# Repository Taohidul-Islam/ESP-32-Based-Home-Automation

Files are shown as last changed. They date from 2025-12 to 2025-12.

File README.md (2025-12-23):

# ESP-32-Based-Home-Automation
<h2>This Board can turn any regular household electric switchboard into a smart Wi-Fi and Remote controlled switchboard.</h2>
<p>Here the board I designed is fail protected, meaning even if my electronic logic fails, the switchboard would work like a regular switchboard. The Automation Board is designed maintaining hierarchy. Meaning the Automation Board can only work only if the main switch from switch board is set to "on". In my logic I don't really turn anything "On". Everything is default "On" and "Off" by switchboard. I can just turn the things "Off" when the switch is "On" by triggering relay and turn the things back to it's default "On" position</p>
<p>N.B. IR remote control is currently unavailable and AC induction fan control channel can be faulty as it is not tested(will test soon).</p>

<P>Here are some screenshots of my PCB And Schematics</P>



Screenshot (96)
Screenshot (97)
Screenshot (98)
Screenshot (99)

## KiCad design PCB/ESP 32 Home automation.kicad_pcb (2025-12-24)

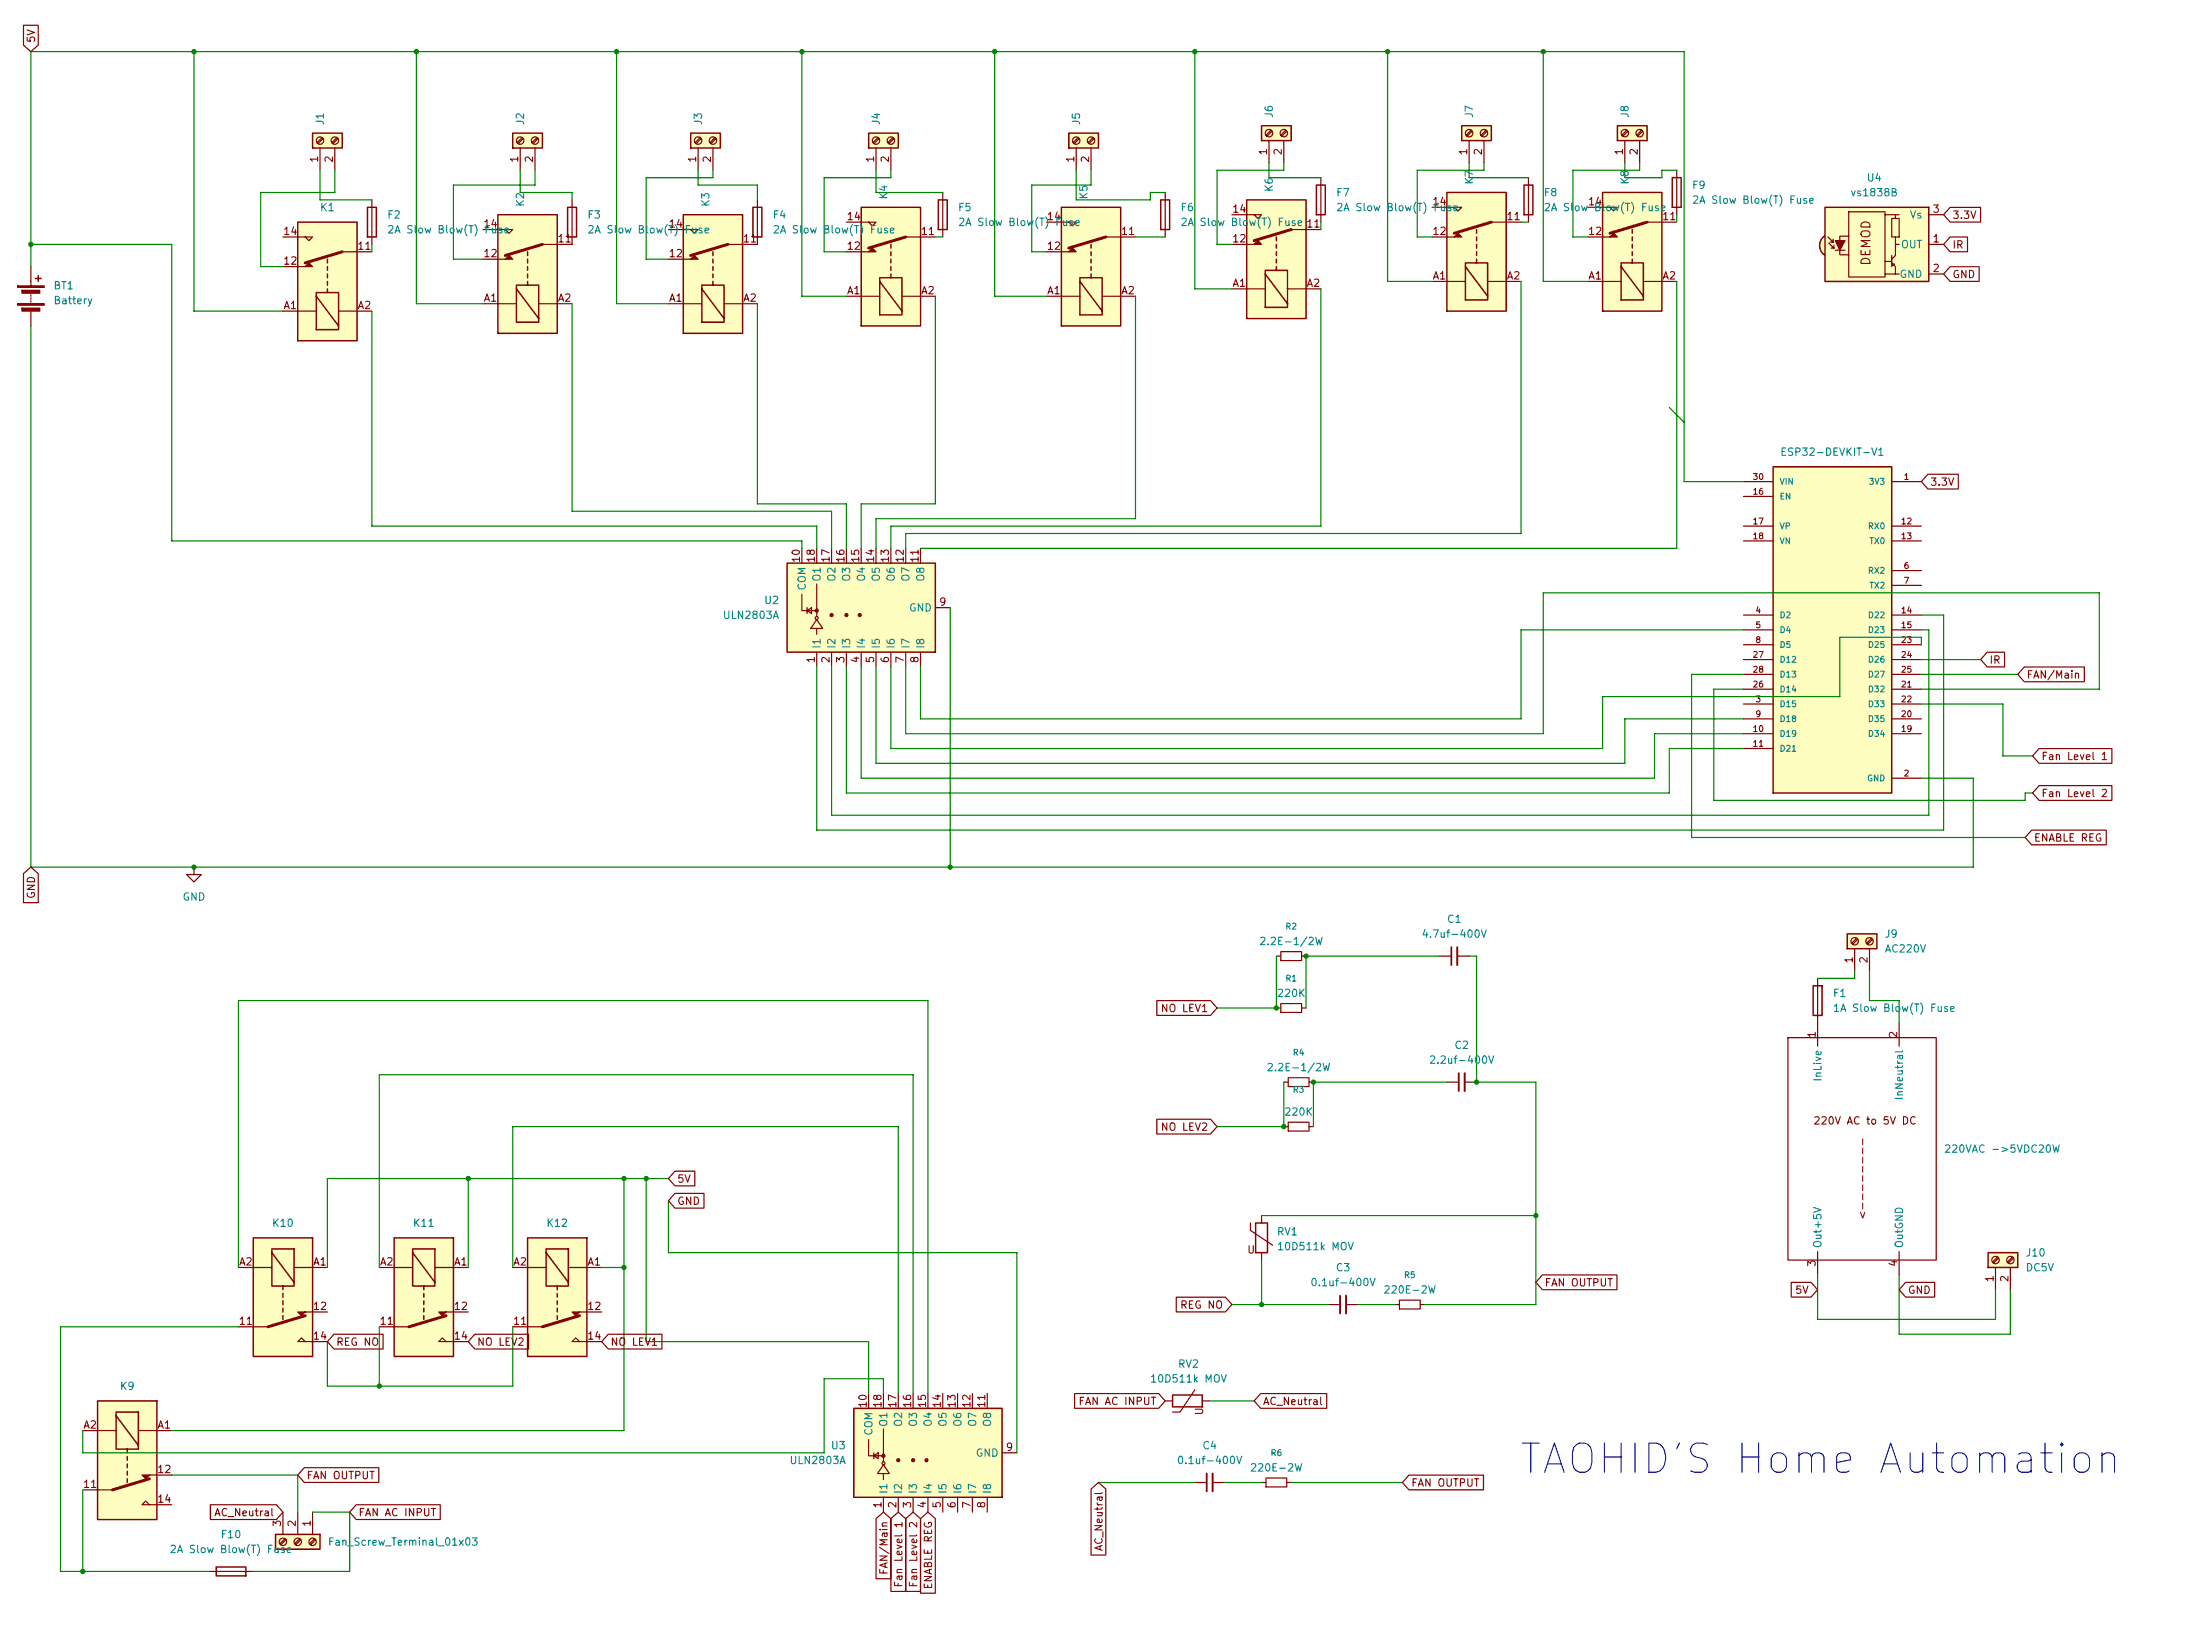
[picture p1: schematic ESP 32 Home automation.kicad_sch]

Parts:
Adapter/Charger1: 220VAC ->5VDC20W; ACtoDC power Adapter. 220V to 5V
BT1: Battery; TerminalBlock_MaiXu_MX126-5.0-02P_1x02_P5.00mm
C1: 4.7uf-400V; C_Rect_L32.0mm_W15.0mm_P27.00mm
C2: 2.2uf-400V; C_Rect_L27.0mm_W9.0mm_P22.00mm
C3, C4: 0.1uf-400V; C_Rect_L13.0mm_W6.5mm_P7.50mm_P10.00mm
F1: 1A Slow Blow(T) Fuse; Fuseholder_Littelfuse_100_series_5x20mm
F2, F3, F4, F5, F6, F7, F8, F9, F10: 2A Slow Blow(T) Fuse; Fuseholder_Littelfuse_100_series_5x20mm
J1, J2, J3, J4, J5, J6, J7, J8: Screw_Terminal_01x02; TerminalBlock_Phoenix_MKDS-1,5-2-5.08_1x02_P5.08mm_Horizont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
J9: AC220V; TerminalBlock_Phoenix_MKDS-1,5-2-5.08_1x02_P5.08mm_Horizont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
J10: DC5V; TerminalBlock_Phoenix_MKDS-1,5-2-5.08_1x02_P5.08mm_Horizont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
J11: Fan_Screw_Terminal_01x03; TerminalBlock_Phoenix_MKDS-1,5-3-5.08_1x03_P5.08mm_Horizont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
K1, K2, K3, K4, K5, K6, K7, K8, K9, K10, K11, K12: JQC-3FF-005-1Z; Relay_SPDT_Hongfa_JQC-3FF_0XX-1Z
R1, R3: 220K; R_Axial_DIN0309_L9.0mm_D3.2mm_P20.32mm_Horizontal
R2, R4: 2.2E-1/2W; R_Axial_DIN0309_L9.0mm_D3.2mm_P20.32mm_Horizontal
R5, R6: 220E-2W; R_Axial_DIN0309_L9.0mm_D3.2mm_P20.32mm_Horizontal
RV1, RV2: 10D511k MOV; RV_Disc_D12mm_W7.5mm_P7.5mm
U1: ESP32-DEVKIT-V1; MODULE_ESP32_DEVKIT_V1; PARTREV N/A
U2, U3: ULN2803A; DIP-18_W7.62mm_Socket_LongPads
U4: vs1838B; Vishay_MOLD-3Pin

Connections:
3.3V: U1.1 (3V3), U4.3 (Vs)
5V: Adapter/Charger1.3 (Out+5V), BT1.1 (+), J10.1, K1.A1, K2.A1, K3.A1, K4.A1, K5.A1, K6.A1, K7.A1, K8.A1, K9.A1, K10.A1, K11.A1, K12.A1, U1.30 (VIN), U2.10 (COM), U3.10 (COM)
AC_Neutral: C4.1, J11.3, RV2.2
ENABLE REG: U1.28 (D13), U3.4 (I4)
FAN AC INPUT: F10.2, J11.1, RV2.1
FAN OUTPUT: C1.2, C2.2, J11.2, K9.12, R5.2, R6.2, RV1.1
FAN/Main: U1.25 (D27), U3.1 (I1)
Fan Level 1: U1.22 (D33), U3.2 (I2)
Fan Level 2: U1.26 (D14), U3.3 (I3)
GND: Adapter/Charger1.4 (OutGND), BT1.2 (-), J10.2, U1.2 (GND), U1.29 (GND), U2.9 (GND), U3.9 (GND), U4.2 (GND)
IR: U1.24 (D26), U4.1 (OUT)
NO LEV1: K12.14, R1.1, R2.1
NO LEV2: K11.14, R3.1, R4.1
unnamed: Adapter/Charger1.1 (InLive), F1.1
unnamed: Adapter/Charger1.2 (InNeutral), J9.2
unnamed: C1.1, R1.2, R2.2
unnamed: C2.1, R3.2, R4.2
unnamed: C3.2, R5.1
unnamed: C4.2, R6.1
unnamed: F2.2, K1.11
unnamed: F3.2, K2.11
unnamed: F4.2, K3.11
unnamed: F5.2, K4.11
unnamed: F6.2, K5.11
unnamed: F7.2, K6.11
unnamed: F8.2, K7.11
unnamed: F9.2, K8.11
unnamed: F10.1, K9.11, K10.11
unnamed: F2.1, J1.1
unnamed: J1.2, K1.12
unnamed: F3.1, J2.1
unnamed: J2.2, K2.12
unnamed: F4.1, J3.1
unnamed: J3.2, K3.12
unnamed: F5.1, J4.1
unnamed: J4.2, K4.12
unnamed: F6.1, J5.1
unnamed: J5.2, K5.12
unnamed: F7.1, J6.1
unnamed: J6.2, K6.12
unnamed: F8.1, J7.1
unnamed: J7.2, K7.12
unnamed: F9.1, J8.1
unnamed: J8.2, K8.12
unnamed: F1.2, J9.1
unnamed: U1.5 (D4), U2.8 (I8)
unnamed: U1.9 (D18), U2.5 (I5)
unnamed: U1.10 (D19), U2.4 (I4)
unnamed: U1.11 (D21), U2.3 (I3)
unnamed: U1.14 (D22), U2.1 (I1)
unnamed: U1.15 (D23), U2.2 (I2)
unnamed: U1.23 (D25), U2.6 (I6)
unnamed: U1.21 (D32), U2.7 (I7)
unnamed: K1.A2, U2.18 (O1)
unnamed: K2.A2, U2.17 (O2)
unnamed: K3.A2, U2.16 (O3)
unnamed: K4.A2, U2.15 (O4)
unnamed: K5.A2, U2.14 (O5)
unnamed: K6.A2, U2.13 (O6)
unnamed: K7.A2, U2.12 (O7)
unnamed: K8.A2, U2.11 (O8)
unnamed: K9.A2, U3.18 (O1)
unnamed: K12.A2, U3.17 (O2)
unnamed: K11.A2, U3.16 (O3)
unnamed: K10.A2, U3.15 (O4)
REG NO: C3.1, K10.14, K11.11, K12.11, RV1.2

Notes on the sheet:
TAOHID'S Home Automation

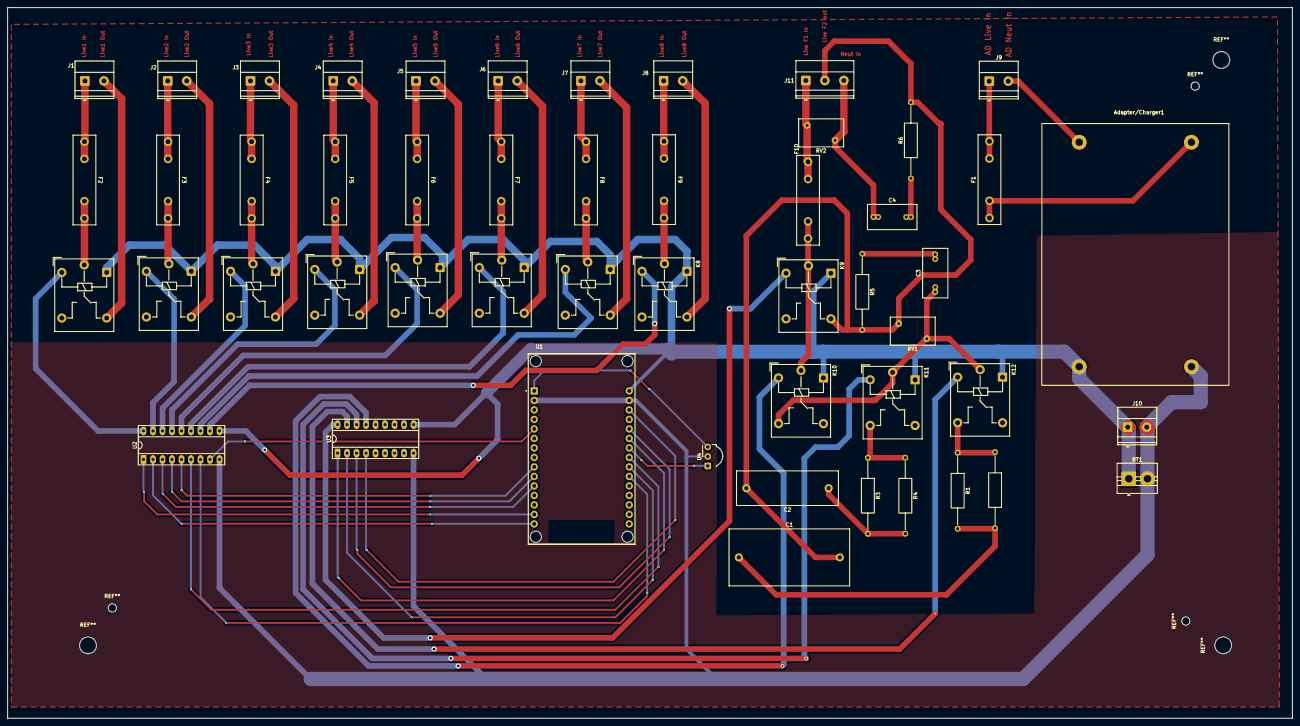
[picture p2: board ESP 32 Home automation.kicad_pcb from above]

Board: 2 copper layers, 343.5 x 190.0 mm, 51 parts (0 on the bottom side), 66 nets.

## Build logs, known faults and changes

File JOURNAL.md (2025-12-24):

<h1>Learned How to Design a PCB</h1>
<h2>December 11, 2025</h2>
<h3>Spent:2.8Hours</h3>
<p>Today through youtube, I learned how to design a PCB on Kikad and started building my first PCB design. Before I worked with breadboard circuitry but never designed a PCB. The one I am designing right now is not related to any project. It's just an tutorial piece. I am gonna make my main project PCB next day. The whole circuitry is on my head right now.
</p>




<h1>Completed my first PCB</h1>
<h2>December 12, 2025</h2>
<h3>Spent:2.5Hours</h3>
<p>Today I completed my basic learning on building PCB and built an mini inverter PCB watching a tutorial. I leant how to make Gerber file and what to send to PCB manufacturer to manufacture my PCB. I hope from the next day, I can start building my project PCB.
</p>



<h1>Started making Schematics, researched on how to control AC.</h1>
<h2>December 13, 2025</h2>
<h3>Spent time: 4 Hours</h3>
<p>Today I started building my project PCB and done research on how to control AC average voltage with a TRIAC and ESP 32. Bought some things to practically learn about TRIACS.
</p>
Today I started building my project PCB and done research on how to control AC average voltage with a TRIAC and ESP 32. Bought some things to practically learn about TRIACS.



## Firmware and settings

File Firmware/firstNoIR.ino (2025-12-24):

#include <WiFi.h>
#include <WebServer.h>
#include <Preferences.h>
#include <ESPmDNS.h>

// GPIO Pin Definitions
#define RELAY_1 22
#define RELAY_2 23
#define RELAY_3 21
#define RELAY_4 19
#define RELAY_5 18
#define RELAY_6 25
#define RELAY_7 32
#define RELAY_8 4

#define FAN_ON 27
#define FAN_LEV1 33
#define FAN_LEV2 14
#define FAN_LEV3 13

#define RESET_PIN 15  // Reset to AP mode button (pull to GND)

// AP Mode Configuration
const char* ap_ssid = "ESP32_SmartSwitch";
const char* ap_password = "12345678";
IPAddress ap_ip(192, 168, 4, 1);
IPAddress ap_gateway(192, 168, 4, 1);
IPAddress ap_subnet(255, 255, 255, 0);

// Static IP Configuration for Home WiFi
IPAddress static_ip(192, 168, 0, 200); // Change this to your desired static IP
IPAddress gateway(192, 168, 0, 1);     // Your router's gateway
IPAddress subnet(255, 255, 255, 0);
IPAddress dns(192, 168, 0, 1);

// Global Variables
WebServer server(80);
Preferences preferences;

bool relayStates[8] = {true, true, true, true, true, true, true, true}; // Default ON
bool fanOnState = true;  // Default ON
int fanLevel = 0;        // 0=OFF, 1=LEV1, 2=LEV2, 3=LEV3
bool useAPMode = true;
String storedSSID = "";
String storedPassword = "";
unsigned long lastStatusPrint = 0;

// GPIO Pins Array
const int relayPins[8] = {RELAY_1, RELAY_2, RELAY_3, RELAY_4, RELAY_5, RELAY_6, RELAY_7, RELAY_8};

void setup() {
  Serial.begin(115200);
  delay(1000);
  
  Serial.println("\n\n========================================");
  Serial.println("   ESP32 Smart Switchboard v1.0");
  Serial.println("========================================\n");
  
  // Initialize Preferences
  preferences.begin("wifi-config", false);
  storedSSID = preferences.getString("ssid", "");
  storedPassword = preferences.getString("password", "");
  useAPMode = preferences.getBool("useAP", true);
  
  Serial.println("Stored SSID: " + (storedSSID.length() > 0 ? storedSSID : "None"));
  Serial.println("Use AP Mode: " + String(useAPMode ? "Yes" : "No"));
  
  // Load saved states
  for(int i = 0; i < 8; i++) {
    relayStates[i] = preferences.getBool(("relay" + String(i)).c_str(), true);
  }
  fanOnState = preferences.getBool("fanOn", true);
  fanLevel = preferences.getInt("fanLevel", 0);
  
  // Initialize GPIO Pins
  initGPIO();
  applyAllStates();
  
  Serial.println("\n--- Network Configuration ---");
  
  // Start WiFi
  if (!useAPMode && storedSSID.length() > 0) {
    connectToWiFi();
  } else {
    startAPMode();
  }
  
  // Setup Web Server Routes
  setupRoutes();
  server.begin();
  
  Serial.println("\n========================================");
  Serial.println("   System Ready!");
  Serial.println("========================================\n");
}

void loop() {
  server.handleClient();
  
  // Print status every 10 seconds if in WiFi mode
  if(WiFi.getMode() == WIFI_STA && millis() - lastStatusPrint > 10000) {
    lastStatusPrint = millis();
    Serial.println("\n--- Status Update ---");
    Serial.print("WiFi Connected: ");
    Serial.println(WiFi.status() == WL_CONNECTED ? "YES" : "NO");
    Serial.print("IP Address: ");
    Serial.println(WiFi.localIP());
    Serial.print("Access at: http://");
    Serial.println(WiFi.localIP());
    Serial.print("Or via: http://smartswitch.local");
    Serial.println("\n-------------------\n");
  }
  
  // Check if reset button is pressed (pulled to GND)
  if(digitalRead(RESET_PIN) == LOW) {
    delay(50); // Debounce
    if(digitalRead(RESET_PIN) == LOW) {
      Serial.println("Reset button pressed! Switching to AP mode...");
      
      // Save AP mode preference
      preferences.putBool("useAP", true);
      
      delay(500);
      ESP.restart();
    }
  }
}

void initGPIO() {
  // Initialize all relay pins
  for(int i = 0; i < 8; i++) {
    pinMode(relayPins[i], OUTPUT);
  }
  
  // Initialize fan control pins
  pinMode(FAN_ON, OUTPUT);
  pinMode(FAN_LEV1, OUTPUT);
  pinMode(FAN_LEV2, OUTPUT);
  pinMode(FAN_LEV3, OUTPUT);
  
  // Initialize reset button with internal pull-up
  pinMode(RESET_PIN, INPUT_PULLUP);
}

void applyAllStates() {
  // Apply relay states (ON = LOW, OFF = HIGH)
  for(int i = 0; i < 8; i++) {
    digitalWrite(relayPins[i], relayStates[i] ? LOW : HIGH);
  }
  
  // Apply fan states
  digitalWrite(FAN_ON, fanOnState ? LOW : HIGH);
  
  if(fanOnState) {
    // Fan is ON, disable all levels
    digitalWrite(FAN_LEV1, LOW);
    digitalWrite(FAN_LEV2, LOW);
    digitalWrite(FAN_LEV3, LOW);
  } else {
    // Fan is OFF, apply level if selected
    applyFanLevel();
  }
}

void applyFanLevel() {
  // First, turn off all levels with delay
  digitalWrite(FAN_LEV1, LOW);
  delay(50);
  digitalWrite(FAN_LEV2, LOW);
  delay(50);
  digitalWrite(FAN_LEV3, LOW);
  delay(50);
  
  // Then turn on the selected level (if any)
  if(fanLevel == 1) {
    digitalWrite(FAN_LEV1, HIGH);
  } else if(fanLevel == 2) {
    digitalWrite(FAN_LEV2, HIGH);
  } else if(fanLevel == 3) {
    digitalWrite(FAN_LEV3, HIGH);
  }
}

void startAPMode() {
  Serial.println("Starting AP Mode...");
  WiFi.mode(WIFI_AP);
  WiFi.softAPConfig(ap_ip, ap_gateway, ap_subnet);
  WiFi.softAP(ap_ssid, ap_password);
  
  Serial.print("AP IP Address: ");
  Serial.println(WiFi.softAPIP());
  Serial.println("Connect to WiFi: " + String(ap_ssid));
  Serial.println("Navigate to: http://192.168.4.1");
}

void connectToWiFi() {
  Serial.println("Connecting to WiFi...");
  Serial.println("SSID: " + storedSSID);
  WiFi.mode(WIFI_STA);
  WiFi.config(static_ip, gateway, subnet, dns);
  WiFi.begin(storedSSID.c_str(), storedPassword.c_str());
  
  int attempts = 0;
  while (WiFi.status() != WL_CONNECTED && attempts < 30) {
    delay(500);
    Serial.print(".");
    attempts++;
  }
  
  if (WiFi.status() == WL_CONNECTED) {
    Serial.println("\nConnected to WiFi!");
    Serial.print("Static IP Address: ");
    Serial.println(WiFi.localIP());
    Serial.print("Gateway: ");
    Serial.println(WiFi.gatewayIP());
    Serial.print("Subnet: ");
    Serial.println(WiFi.subnetMask());
    Serial.print("DNS: ");
    Serial.println(WiFi.dnsIP());
    
    // Setup mDNS
    if(MDNS.begin("smartswitch")) {
      Serial.println("mDNS started: http://smartswitch.local");
    }
  } else {
    Serial.println("\n❌ Failed to connect to WiFi!");
    Serial.println("Reason: " + String(WiFi.status()));
    Serial.println("Falling back to AP Mode...");
    
    // Clear saved credentials and switch to AP mode
    preferences.putBool("useAP", true);
    startAPMode();
  }
}

void setupRoutes() {
  server.on("/", HTTP_GET, handleRoot);
  server.on("/config", HTTP_GET, handleConfig);
  server.on("/savewifi", HTTP_POST, handleSaveWiFi);
  server.on("/useap", HTTP_POST, handleUseAP);
  server.on("/toggle", HTTP_POST, handleToggle);
  server.on("/fanon", HTTP_POST, handleFanOn);
  server.on("/fanlevel", HTTP_POST, handleFanLevel);
  server.on("/status", HTTP_GET, handleStatus);
}

void handleRoot() {
  String html = "<!DOCTYPE html><html><head>";
  html += "<meta name='viewport' content='width=device-width, initial-scale=1.0'>";
  html += "<title>Smart Switchboard</title>";
  html += "<style>";
  html += "body{font-family:Arial;margin:0;padding:20px;background:#f0f0f0;}";
  html += ".container{max-width:600px;margin:0 auto;background:white;padding:20px;border-radius:10px;box-shadow:0 2px 10px rgba(0,0,0,0.1);}";
  html += "h1{color:#333;text-align:center;margin-bottom:30px;}";
  html += ".switch-row{display:flex;justify-content:space-between;align-items:center;padding:15px;border-bottom:1px solid #eee;}";
  html += ".switch-row:last-child{border-bottom:none;}";
  html += ".label{font-size:16px;font-weight:500;}";
  html += ".toggle{position:relative;width:60px;height:30px;background:#ccc;border-radius:30px;cursor:pointer;transition:0.3s;}";
  html += ".toggle.on{background:#4CAF50;}";
  html += ".toggle-slider{position:absolute;top:3px;left:3px;width:24px;height:24px;background:white;border-radius:50%;transition:0.3s;}";
  html += ".toggle.on .toggle-slider{left:33px;}";
  html += ".fan-section{background:#f9f9f9;padding:15px;margin-top:20px;border-radius:8px;}";
  html += ".level-buttons{display:flex;gap:10px;margin-top:10px;}";
  html += ".level-btn{flex:1;padding:10px;border:none;border-radius:5px;cursor:pointer;font-weight:bold;transition:0.3s;}";
  html += ".level-btn.active{background:#2196F3;color:white;}";
  html += ".level-btn.inactive{background:#e0e0e0;color:#666;}";
  html += ".config-btn{display:block;width:100%;padding:15px;margin-top:20px;background:#FF9800;color:white;border:none;border-radius:5px;font-size:16px;cursor:pointer;}";
  html += ".config-btn:hover{background:#F57C00;}";
  html += ".info{text-align:center;margin-top:20px;color:#666;font-size:14px;}";
  html += "</style>";
  html += "</head><body>";
  html += "<div class='container'>";
  html += "<h1>Smart Switchboard</h1>";
  
  // Regular switches
  for(int i = 0; i < 8; i++) {
    html += "<div class='switch-row'>";
    html += "<span class='label'>Switch " + String(i+1) + "</span>";
    html += "<div class='toggle " + String(relayStates[i] ? "on" : "") + "' onclick='toggleRelay(" + String(i) + ")'>";
    html += "<div class='toggle-slider'></div></div></div>";
  }
  
  // Fan section
  html += "<div class='fan-section'>";
  html += "<div class='switch-row'>";
  html += "<span class='label'>Fan Power</span>";
  html += "<div class='toggle " + String(fanOnState ? "on" : "") + "' onclick='toggleFan()'>";
  html += "<div class='toggle-slider'></div></div></div>";
  
  if(!fanOnState) {
    html += "<div class='level-buttons'>";
    html += "<button class='level-btn " + String(fanLevel == 1 ? "active" : "inactive") + "' onclick='setFanLevel(1)'>Level 1</button>";
    html += "<button class='level-btn " + String(fanLevel == 2 ? "active" : "inactive") + "' onclick='setFanLevel(2)'>Level 2</button>";
    html += "<button class='level-btn " + String(fanLevel == 3 ? "active" : "inactive") + "' onclick='setFanLevel(3)'>Level 3</button>";
    html += "</div>";
  }
  html += "</div>";
  
  html += "<button class='config-btn' onclick='location.href=\"/config\"'>WiFi Configuration</button>";
  
  html += "<div class='info'>";
  if(WiFi.getMode() == WIFI_AP) {
    html += "Mode: Access Point<br>IP: " + WiFi.softAPIP().toString();
  } else {
    html += "Mode: WiFi Station<br>IP: " + WiFi.localIP().toString();
  }
  html += "</div>";
  
  html += "</div>";
  
  // JavaScript
  html += "<script>";
  html += "function toggleRelay(num){fetch('/toggle?relay='+num,{method:'POST'}).then(()=>location.reload());}";
  html += "function toggleFan(){fetch('/fanon',{method:'POST'}).then(()=>location.reload());}";
  html += "function setFanLevel(lev){fetch('/fanlevel?level='+lev,{method:'POST'}).then(()=>location.reload());}";
  html += "</script>";
  html += "</body></html>";
  
  server.send(200, "text/html", html);
}

void handleConfig() {
  String html = "<!DOCTYPE html><html><head>";
  html += "<meta name='viewport' content='width=device-width, initial-scale=1.0'>";
  html += "<title>WiFi Configuration</title>";
  html += "<style>";
  html += "body{font-family:Arial;margin:0;padding:20px;background:#f0f0f0;}";
  html += ".container{max-width:500px;margin:0 auto;background:white;padding:30px;border-radius:10px;box-shadow:0 2px 10px rgba(0,0,0,0.1);}";
  html += "h1{color:#333;text-align:center;}";
  html += ".form-group{margin:20px 0;}";
  html += "label{display:block;margin-bottom:5px;font-weight:500;}";
  html += "input{width:100%;padding:10px;border:1px solid #ddd;border-radius:5px;box-sizing:border-box;}";
  html += "button{width:100%;padding:15px;margin-top:10px;border:none;border-radius:5px;font-size:16px;cursor:pointer;font-weight:bold;}";
  html += ".btn-primary{background:#4CAF50;color:white;}";
  html += ".btn-secondary{background:#2196F3;color:white;}";
  html += ".btn-back{background:#666;color:white;margin-top:20px;}";
  html += "button:hover{opacity:0.9;}";
  html += ".info{background:#e3f2fd;padding:15px;border-radius:5px;margin-bottom:20px;}";
  html += "</style>";
  html += "</head><body>";
  html += "<div class='container'>";
  html += "<h1>WiFi Setup</h1>";
  
  html += "<div class='info'>Current Mode: " + String(WiFi.getMode() == WIFI_AP ? "Access Point" : "WiFi Station") + "</div>";
  
  html += "<form action='/savewifi' method='post'>";
  html += "<div class='form-group'><label>WiFi SSID:</label><input type='text' name='ssid' value='" + storedSSID + "' required></div>";
  html += "<div class='form-group'><label>WiFi Password:</label><input type='password' name='password' value='" + storedPassword + "'></div>";
  html += "<button type='submit' class='btn-primary'>Save & Connect to WiFi</button>";
  html += "</form>";
  
  html += "<form action='/useap' method='post'>";
  html += "<button type='submit' class='btn-secondary'>Use AP Mode Only</button>";
  html += "</form>";
  
  html += "<button class='btn-back' onclick='location.href=\"/\"'>Back to Controls</button>";
  
  html += "</div>";
  html += "</body></html>";
  
  server.send(200, "text/html", html);
}

void handleSaveWiFi() {
  if(server.hasArg("ssid")) {
    storedSSID = server.arg("ssid");
    storedPassword = server.arg("password");
    
    preferences.putString("ssid", storedSSID);
    preferences.putString("password", storedPassword);
    preferences.putBool("useAP", false);
    
    String html = "<!DOCTYPE html><html><head><meta http-equiv='refresh' content='5;url=/'></head><body style='font-family:Arial;text-align:center;padding:50px;'>";
    html += "<h2>WiFi Settings Saved!</h2>";
    html += "<p>Connecting to: " + storedSSID + "</p>";
    html += "<p>The device will now restart and connect to your WiFi.</p>";
    html += "<p>Find the device at: http://" + static_ip.toString() + "</p>";
    html += "<p>Redirecting in 5 seconds...</p>";
    html += "</body></html>";
    
    server.send(200, "text/html", html);
    
    delay(2000);
    ESP.restart();
  }
}

void handleUseAP() {
  preferences.putBool("useAP", true);
  
  String html = "<!DOCTYPE html><html><head><meta http-equiv='refresh' content='3;url=/'></head><body style='font-family:Arial;text-align:center;padding:50px;'>";
  html += "<h2>AP Mode Enabled!</h2>";
  html += "<p>The device will restart in AP mode.</p>";
  html += "<p>Connect to: " + String(ap_ssid) + "</p>";
  html += "<p>Access at: http://192.168.4.1</p>";
  html += "</body></html>";
  
  server.send(200, "text/html", html);
  
  delay(2000);
  ESP.restart();
}

void handleToggle() {
  if(server.hasArg("relay")) {
    int relayNum = server.arg("relay").toInt();
    if(relayNum >= 0 && relayNum < 8) {
      relayStates[relayNum] = !relayStates[relayNum];
      digitalWrite(relayPins[relayNum], relayStates[relayNum] ? LOW : HIGH);
      preferences.putBool(("relay" + String(relayNum)).c_str(), relayStates[relayNum]);
      server.send(200, "text/plain", "OK");
      return;
    }
  }
  server.send(400, "text/plain", "Bad Request");
}

void handleFanOn() {
  fanOnState = !fanOnState;
  digitalWrite(FAN_ON, fanOnState ? LOW : HIGH);
  
  if(fanOnState) {
    // Fan turned ON, disable all levels
    fanLevel = 0;
    digitalWrite(FAN_LEV1, LOW);
    digitalWrite(FAN_LEV2, LOW);
    digitalWrite(FAN_LEV3, LOW);
  }
  
  preferences.putBool("fanOn", fanOnState);
  preferences.putInt("fanLevel", fanLevel);
  
  server.send(200, "text/plain", "OK");
}

void handleFanLevel() {
  if(server.hasArg("level")) {
    int level = server.arg("level").toInt();
    if(level >= 1 && level <= 3 && !fanOnState) {
      fanLevel = level;
      applyFanLevel();
      preferences.putInt("fanLevel", fanLevel);
      server.send(200, "text/plain", "OK");
      return;
    }
  }
  server.send(400, "text/plain", "Bad Request");
}

void handleStatus() {
  String json = "{";
  json += "\"relays\":[";
  for(int i = 0; i < 8; i++) {
    json += String(relayStates[i] ? "true" : "false");
    if(i < 7) json += ",";
  }
  json += "],";
  json += "\"fanOn\":" + String(fanOnState ? "true" : "false") + ",";
  json += "\"fanLevel\":" + String(fanLevel) + ",";
  json += "\"mode\":\"" + String(WiFi.getMode() == WIFI_AP ? "AP" : "STA") + "\",";
  json += "\"ip\":\"" + (WiFi.getMode() == WIFI_AP ? WiFi.softAPIP().toString() : WiFi.localIP().toString()) + "\"";
  json += "}";
  
  server.send(200, "application/json", json);
}

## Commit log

2025-12-23 Revise IR remote note and add caution for fan control
    Updated the note about IR remote control and added a caution regarding the AC induction fan control channel.
2025-12-24 Create PCB
2025-12-26 Revise BOM.csv with new product entries and fixes
    Updated BOM.csv to include additional product details and corrected formatting issues.
    [BOM.csv]
2026-01-13 Update and rename BOM2..csv to BOM.csv
    [BOM.csv]
